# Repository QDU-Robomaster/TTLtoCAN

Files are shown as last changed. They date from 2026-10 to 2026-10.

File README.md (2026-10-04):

# 项目名称
TTLtoCANforTOF

## 项目简介
面向 ToF 设备的 TTL UART 转 CAN 通信模块，设计目标是通过 24V 输入为 ToF 提供 5V 电源，并由 STM32 完成串口数据与 CAN 报文之间的转换。

## PCB预览

以下预览基于 2026-10-04 23:51 保存的 PCB 文件重新生成。部分器件未配置三维模型，实际装配以封装和 BOM 为准。

正面：

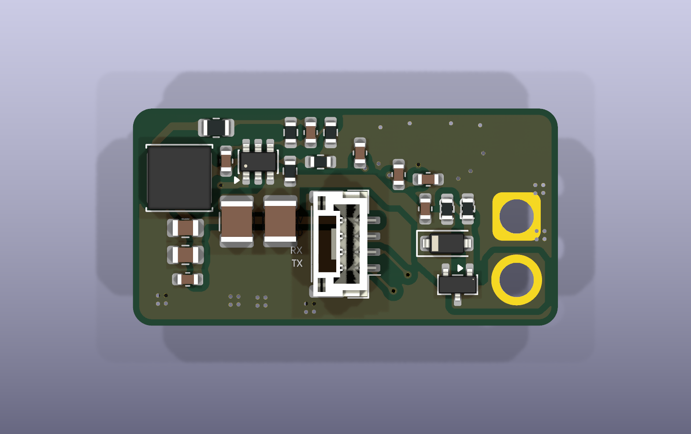
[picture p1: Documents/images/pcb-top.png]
PCB 正面


背面：

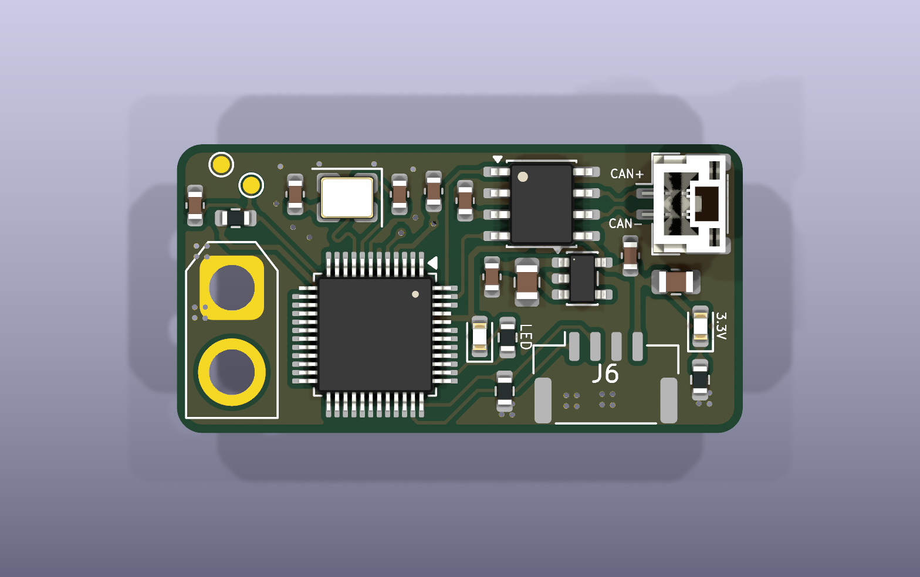
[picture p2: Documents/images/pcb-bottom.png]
PCB 背面


## 主要参数
PCB 尺寸  36.00 × 20.05 mm，圆角矩形 
层数 / 板厚  2 层 / 1.6 mm 
输入电源  设计标称 24V，经 J4 输入 
ToF 电源  设计目标 5V，经 J3 第 4 脚输出 
板上逻辑电源  3.3V 
主控  STM32G0B1CBTx，LQFP-48 
通信接口  UART（J3）、CAN（J2） 
调试接口  SWD（J6） 
## 接口定义
J4：电源输入 AMASS XT30U-F，2Pin  
    1：GND；
    2：VCC_IN（标称 24V 输入） 
J2：CAN  JST GH，2Pin，1.25 mm  
    1：CAN− / CAN_L；
    2：CAN+ / CAN_H 
J3：ToF  JST GH，4Pin，1.25 mm  
    1：USART1_TX（模块输出，接设备 RX）；
    2：USART1_RX（模块输入，接设备 TX）；
    3：GND；
    4：5V 电源输出 
J6：SWD  Molex CLIK-Mate 502386-0470，4Pin，1.25 mm  
    1：SWDIO；
    2：SWCLK；
    3：GND；
    4：3.3V 参考电源 
## 项目扩展叙述

电源部分通过 TPS54202 将输入电源降压至设计目标 5V，再由 ME6211 产生板上 3.3V。STM32 连接 ToF 的 UART，并通过 CAN 收发器接入总线。通信转换需要配套固件，当前仓库未提供固件及协议定义。

详细的接口接线、工程打开方式、生产资料与调试安排见 [工程说明文档](Documents/工程说明.md)。

## 主要器件
U1  TPS54202DDC  开关降压，设计用于产生 5V 
U2  ME6211C33M5  3.3V 线性稳压 
U3  STM32G0B1CBTx  通信处理主控 
U6  TCAN3413DR（当前 Value）  CAN 收发器
Q2  Si2309CDS-T1-GE3  输入侧 P 沟道 MOS 管 
D3  BZT52-C12  输入保护电路中的稳压管 
L1  15µH  降压电感 
Y1  X32258MSB  MCU 外部晶振
## 制造资料指路
制造和装配输出位于 [Production_documents/](Production_documents/)，各子目录用途见 [工程说明文档](Documents/工程说明.md)。
使用 KiCad 10.0.x 打开根目录的 [TTLtoCANforTOF.kicad_pro](TTLtoCANforTOF.kicad_pro)，再进入原理图或 PCB 编辑器。
 [TTLtoCANforTOF.kicad_sch](TTLtoCANforTOF.kicad_sch)  当前原理图 
 [TTLtoCANforTOF.kicad_pcb](TTLtoCANforTOF.kicad_pcb)  当前 PCB 
 [sym-lib-table](sym-lib-table)  项目符号库路径配置  [BOM/](BOM/)  设计物料清单 
 [Documents/](Documents/)  项目说明、预览图和检查报告 
 [3Dmodel/TTLtoCANforTOF.step](3Dmodel/TTLtoCANforTOF.step)  整板 STEP 模型 
 [Production_documents/](Production_documents/)  生产输出资料 
 [History/](History/)  历史工程快照，不作为当前生产依据

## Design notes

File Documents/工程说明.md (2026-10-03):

# TTLtoCANforTOF 工程说明

更新日期：2026-10-03。本文依据当前仓库中的原理图、PCB、BOM 和生产目录编写；设计目标与实测结果分开记录。

## 1. 项目用途

本工程用于将 ToF 设备的 TTL UART 数据接入 CAN 总线，同时利用外部标称 24V 电源为 ToF 提供设计目标为 5V 的电源输出。

STM32G0B1CBTx 负责串口数据接收、解析和 CAN 报文组织，CAN 收发器负责连接物理总线。

## 2. 系统组成与主要参数

电源路径：J4 电源输入 → 输入保护电路 → TPS54202 降压电路 → 5V；5V 分别供给 J3 的 ToF 电源接口和 ME6211 线性稳压器，后者产生板上 3.3V。

通信路径：J3 的 UART 信号 ↔ STM32G0B1 ↔ CAN 收发器 ↔ J2 的 CAN 总线。J6 提供 SWD 调试接口。

| 项目 | 当前设计 |
| --- | --- |
| 工程名称 | TTLtoCANforTOF |
| 设计工具 | KiCad 10.0.x；已有导出和检查使用 10.0.5 |
| 板框尺寸 | 36.00 × 20.05 mm |
| 外形 | 圆角矩形，板框圆角半径 1.5 mm |
| PCB 层数 / 板厚 | 2 层 / 1.6 mm |
| 电源输入 | 标称 24V，J4 输入 |
| ToF 电源输出 | 设计目标 5V，J3 第 4 脚 |
| 板上逻辑电源 | 3.3V |
| 主控 | STM32G0B1CBTx，LQFP-48 |
| 外设接口 | UART、CAN、SWD |

## 3. 接口与连接方式

### J4：电源输入

连接器封装：AMASS XT30U-F，2Pin。

| 引脚 | 网络 | 用途 |
| --- | --- | --- |
| 1 | GND | 电源负极 |
| 2 | VCC_IN | 标称 24V 电源正极 |

### J2：CAN 接口

连接器封装：JST GH，2Pin，1.25 mm 间距。

| 引脚 | 网络 | 用途 |
| --- | --- | --- |
| 1 | CAN− | CAN_L |
| 2 | CAN+ | CAN_H |

### J3：ToF 接口

连接器封装：JST GH，4Pin，1.25 mm 间距。

| 引脚 | 网络 | 用途 |
| --- | --- | --- |
| 1 | USART1_TX | 模块串口发送，接 ToF 的 RX |
| 2 | USART1_RX | 模块串口接收，接 ToF 的 TX |
| 3 | GND | ToF 信号地及供电地 |
| 4 | 5V | ToF 电源输出 |

### J6：SWD 调试接口

连接器封装：Molex CLIK-Mate 502386-0470，4Pin，1.25 mm 间距。

| 引脚 | 网络 | 用途 |
| --- | --- | --- |
| 1 | SWDIO | SWD 数据 |
| 2 | SWCLK | SWD 时钟 |
| 3 | GND | 调试器参考地 |
| 4 | +3.3V | 目标板电压参考 |

## 4. 主要器件

| 位号 | 型号 / 数值 | 作用 |
| --- | --- | --- |
| U1 | TPS54202DDC | 开关降压，设计用于 24V 转 5V |
| U2 | ME6211C33M5 | 产生板上 3.3V |
| U3 | STM32G0B1CBTx | 串口和 CAN 通信处理 |
| U6 | TCAN3413DR（当前 Value） | CAN 总线收发器 |
| Q2 | Si2309CDS-T1-GE3 | 输入侧 P 沟道 MOS 管 |
| D3 | BZT52-C12 | 输入保护电路中的稳压管 |
| L1 | 15µH | 降压储能电感 |
| Y1 | X32258MSB | MCU 外部晶振 |

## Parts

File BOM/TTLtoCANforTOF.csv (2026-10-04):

编号 | 位号 | 封装 | 数量 | 名称 | 供应商编号
1 | C1, C2, C10, C12, C13, C14, C18, C19, C20, C21 | C_0603_1608Metric | 10 | 0.1uF
2 | C3, C4 | C_1210_3225Metric | 2 | 22uF
3 | C6, C8, C11 | C_0805_2012Metric | 3 | 22uF
4 | C7 | C_0603_1608Metric | 1 | 75pF
5 | C9 | C_0805_2012Metric | 1 | 10uF
6 | C15 | C_0603_1608Metric | 1 | 4.7uF
7 | C16, C17 | C_0603_1608Metric | 2 | 22pF
8 | D1, D2 | LED_0603_1608Metric | 2 | LED
9 | D3 | D_SOD-123 | 1 | BZT52-C12
10 | J2 | JST_GH_BM02B-GHS-TBT_1x02-1MP_P1.25mm_Vertical | 1 | CAN
11 | J3 | JST_GH_BM04B-GHS-TBT_1x04-1MP_P1.25mm_Vertical | 1 | TOF
12 | J4 | AMASS_XT30U-F_1x02_P5.0mm_Vertical | 1 | XT30
13 | J6 | Molex_CLIK-Mate_502386-0470_1x04-1MP_P1.25mm_Horizontal | 1 | SWD
14 | L1 | L_APV_ANR5020 | 1 | 15uH
15 | Q2 | SOT-23 | 1 | Si2309CDS-T1-GE3
16 | R1 | R_0603_1608Metric | 1 | 500kΩ
17 | R2, R4, R7, R9 | R_0603_1608Metric | 4 | 100kΩ
18 | R3 | R_0805_2012Metric | 1 | 0Ω
19 | R5 | R_0603_1608Metric | 1 | 13.3kΩ
20 | R6, R8 | R_0603_1608Metric | 2 | 10kΩ
21 | R10, R11 | R_0603_1608Metric | 2 | 1kΩ
22 | TP1 | TestPoint_Pad_D1.0mm | 1 | RST
23 | TP2 | TestPoint_Pad_D1.0mm | 1 | GND
24 | U1 | SOT-23-6 | 1 | TPS54202DDC
25 | U2 | SOT-23-5 | 1 | ME6211C33M5
26 | U3 | LQFP-48_7x7mm_P0.5mm | 1 | STM32G0B1CBTx
27 | U6 | SOIC-8_3.9x4.9mm_P1.27mm | 1 | TCAN3413DR
28 | Y1 | Crystal_SMD_3225-4Pin_3.2x2.5mm | 1 | X32258MSB

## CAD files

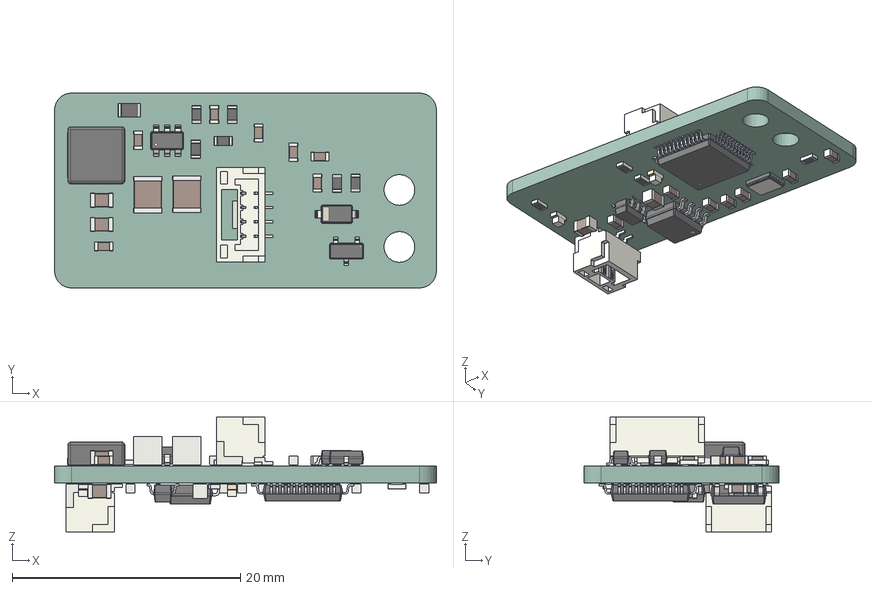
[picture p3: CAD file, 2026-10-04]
3Dmodel/TTLtoCANforTOF.step
33.5 x 17.1 x 10.1 mm
R_0603_1608Metric x 10
C_0603_1608Metric x 14
SOT-23
D_SOD-123
R_0805_2012Metric
C_0805_2012Metric x 4
JST_BM04B_GHS_TBT
L_APV_ANR5020
SOT-23-6
C_1210_3225Metric x 2
LED_0603_1608Metric x 2
SOIC-8_3.9x4.9mm_P1.27mm
JST_BM02B_GHS_TBT
LQFP-48_7x7mm_P0.5mm
Crystal_SMD_3225-4Pin_3.2x2.5mm
SOT-23-5
TTL438A_PCB

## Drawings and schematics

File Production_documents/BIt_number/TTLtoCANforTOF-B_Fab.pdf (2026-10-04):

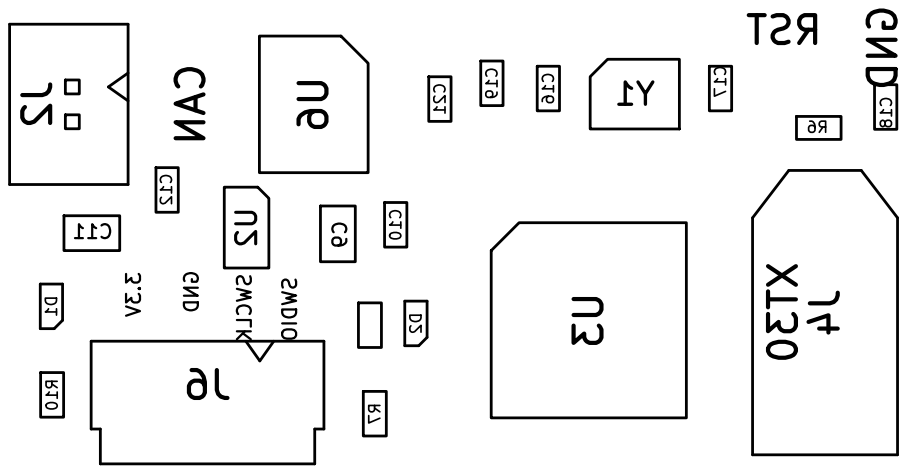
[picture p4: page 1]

3.3V GND SWCLK SWDIO J6 D1 R7 C12 D2 C19 C16 RST

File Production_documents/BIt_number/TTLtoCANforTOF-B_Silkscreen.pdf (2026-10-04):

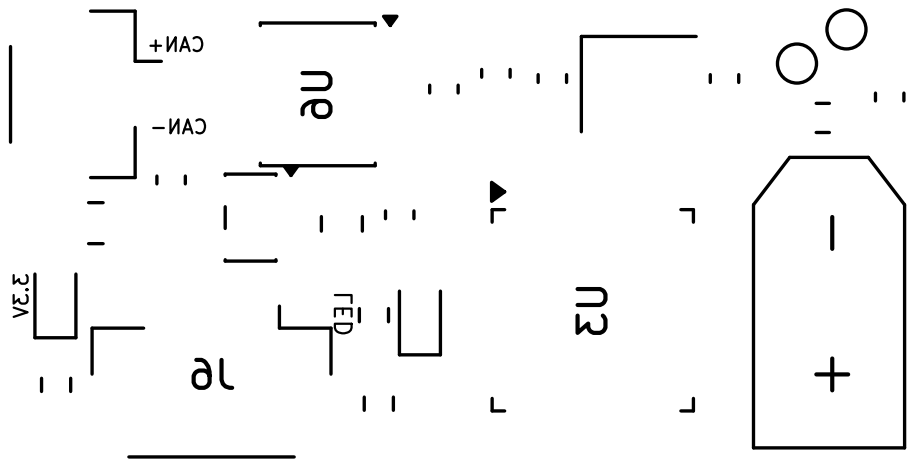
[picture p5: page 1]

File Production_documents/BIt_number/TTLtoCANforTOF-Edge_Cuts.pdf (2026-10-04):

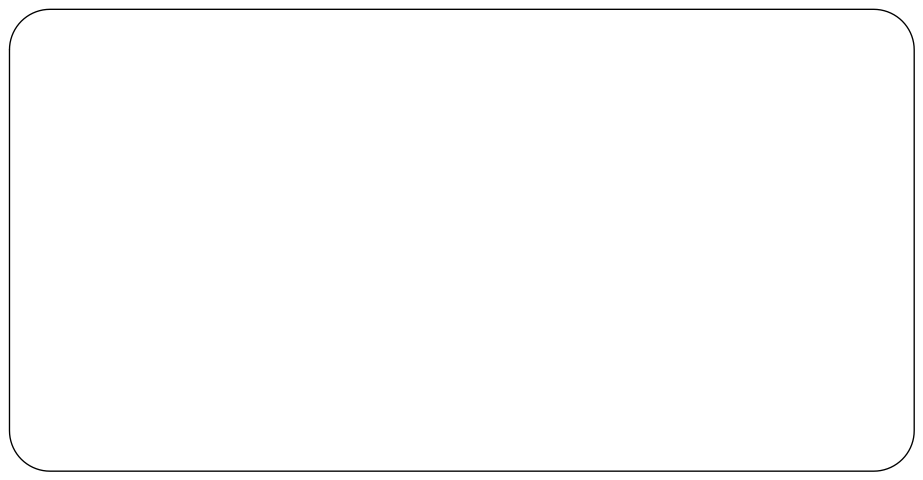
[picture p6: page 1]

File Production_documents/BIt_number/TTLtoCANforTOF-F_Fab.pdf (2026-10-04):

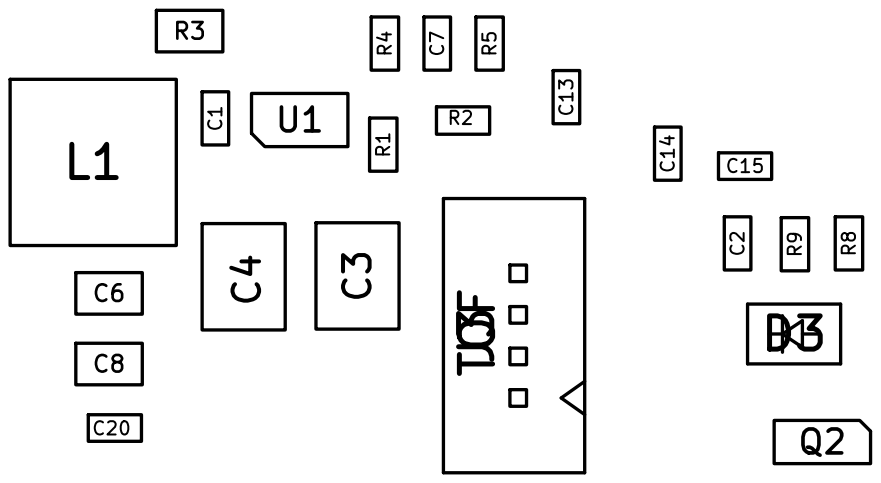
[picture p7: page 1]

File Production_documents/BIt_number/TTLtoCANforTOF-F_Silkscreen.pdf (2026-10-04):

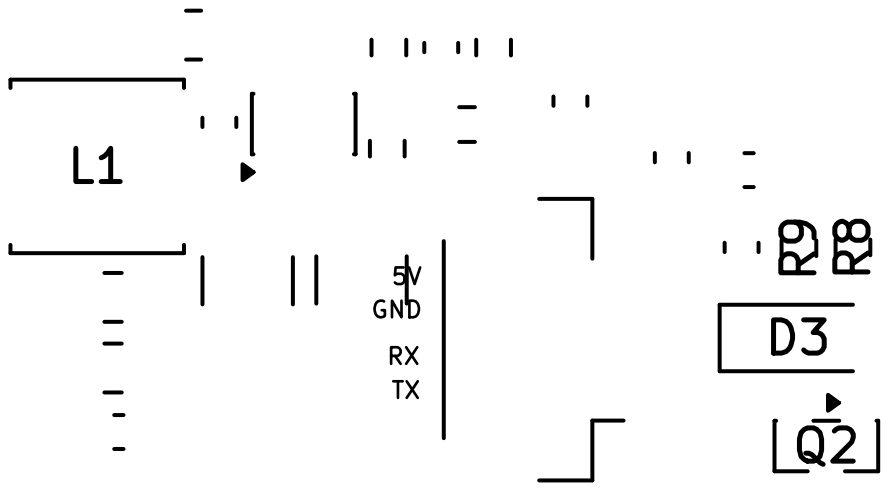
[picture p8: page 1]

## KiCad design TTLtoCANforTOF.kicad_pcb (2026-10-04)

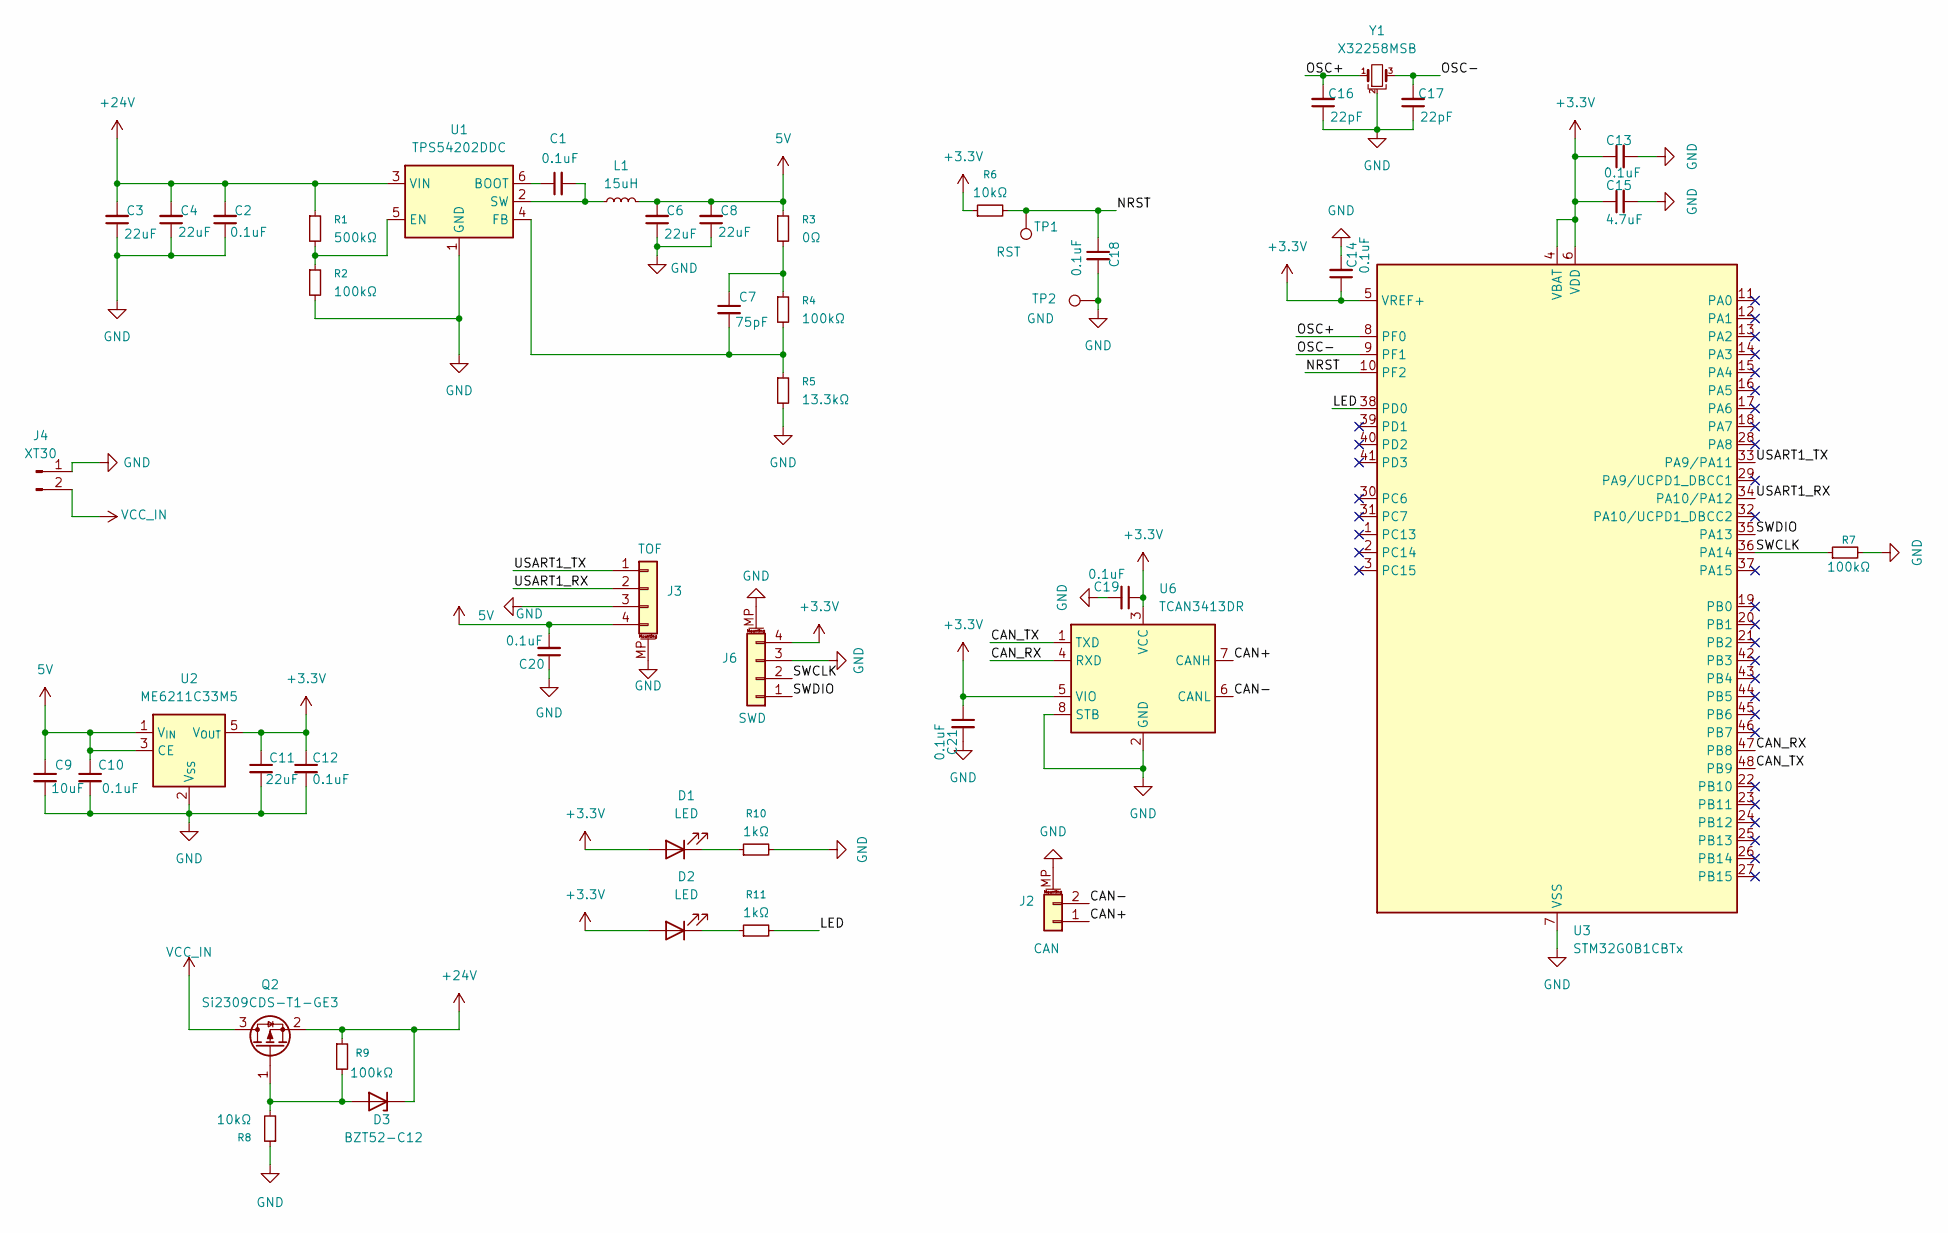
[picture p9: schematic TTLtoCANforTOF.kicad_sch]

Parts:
C1, C2, C10, C12, C13, C14, C18, C19, C20, C21: 0.1uF; C_0603_1608Metric
C3, C4: 22uF; C_1210_3225Metric
C6, C8, C11: 22uF; C_0805_2012Metric
C7: 75pF; C_0603_1608Metric
C9: 10uF; C_0805_2012Metric
C15: 4.7uF; C_0603_1608Metric
C16, C17: 22pF; C_0603_1608Metric
D1, D2: LED; LED_0603_1608Metric
D3: BZT52-C12; D_SOD-123
J2: CAN; JST_GH_BM02B-GHS-TBT_1x02-1MP_P1.25mm_Vertical
J3: TOF; JST_GH_BM04B-GHS-TBT_1x04-1MP_P1.25mm_Vertical
J4: XT30; AMASS_XT30U-F_1x02_P5.0mm_Vertical
J6: SWD; Molex_CLIK-Mate_502386-0470_1x04-1MP_P1.25mm_Horizontal
L1: 15uH; L_APV_ANR5020
Q2: Si2309CDS-T1-GE3; SOT-23
R1: 500kΩ; R_0603_1608Metric
R2, R4, R7, R9: 100kΩ; R_0603_1608Metric
R3: 0Ω; R_0805_2012Metric
R5: 13.3kΩ; R_0603_1608Metric
R6, R8: 10kΩ; R_0603_1608Metric
R10, R11: 1kΩ; R_0603_1608Metric
TP1: RST; TestPoint_Pad_D1.0mm
TP2: GND; TestPoint_Pad_D1.0mm
U1: TPS54202DDC; SOT-23-6
U2: ME6211C33M5; SOT-23-5
U3: STM32G0B1CBTx; LQFP-48_7x7mm_P0.5mm
U6: TCAN3413DR; SOIC-8_3.9x4.9mm_P1.27mm
Y1: X32258MSB; Crystal_SMD_3225-4Pin_3.2x2.5mm

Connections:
5V: C6.2, C8.2, C9.1, C10.1, C20.2, J3.4, L1.1, R3.1, U2.1 (V_{IN}), U2.3 (CE)
+3.3V: C11.1, C12.1, C13.1, C14.1, C15.1, C19.1, C21.1, D1.2 (A), D2.2 (A), J6.4, R6.1, U2.5 (V_{OUT}), U3.4 (VBAT), U3.5 (VREF+), U3.6 (VDD), U6.3 (VCC), U6.5 (VIO)
+24V: C2.2, C3.2, C4.2, D3.1 (K), Q2.2 (S), R1.1, R9.1, U1.3 (VIN)
/CAN+: J2.1, U6.7 (CANH)
/CAN-: J2.2, U6.6 (CANL)
/CAN_RX: U3.47 (PB8), U6.4 (RXD)
/CAN_TX: U3.48 (PB9), U6.1 (TXD)
/LED: R11.2, U3.38 (PD0)
/NRST: C18.1, R6.2, TP1.1 (1_1), U3.10 (PF2)
/OSC+: C16.2, U3.8 (PF0), Y1.1
/OSC-: C17.2, U3.9 (PF1), Y1.3
/SWCLK: J6.2, R7.1, U3.36 (PA14)
/SWDIO: J6.1, U3.35 (PA13)
/USART1_RX: J3.2, U3.34 (PA10/PA12)
/USART1_TX: J3.1, U3.33 (PA9/PA11)
GND: C2.1, C3.1, C4.1, C6.1, C8.1, C9.2, C10.2, C11.2, C12.2, C13.2, C14.2, C15.2, C16.1, C17.1, C18.2, C19.2, C20.1, C21.2, J2.MP (MountPin), J3.3, J3.MP (MountPin), J4.1, J6.3, J6.MP (MountPin), R2.2, R5.2, R7.2, R8.1, R10.2, TP2.1 (1_1), U1.1 (GND), U2.2 (V_{SS}), U3.7 (VSS), U6.2 (GND), U6.8 (STB), Y1.2, Y1.4
unnamed: C7.1, R3.2, R4.1
unnamed: D1.1 (K), R10.1
unnamed: D2.1 (K), R11.1
unnamed: D3.2 (A), Q2.1 (G), R8.2, R9.2
unnamed: C1.1, U1.6 (BOOT)
unnamed: R1.2, R2.1, U1.5 (EN)
unnamed: C7.2, R4.2, R5.1, U1.4 (FB)
unnamed: C1.2, L1.2, U1.2 (SW)
VCC_IN: J4.2, Q2.3 (D)

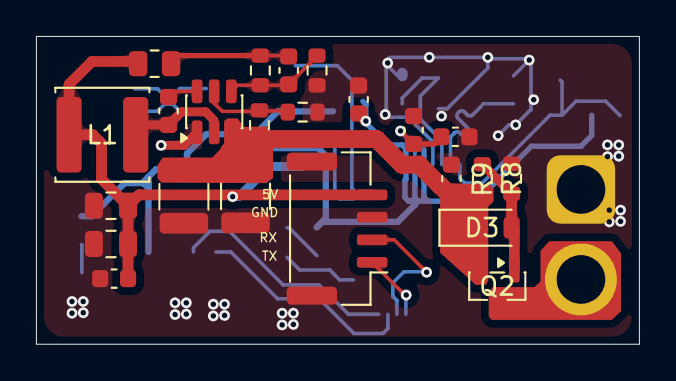
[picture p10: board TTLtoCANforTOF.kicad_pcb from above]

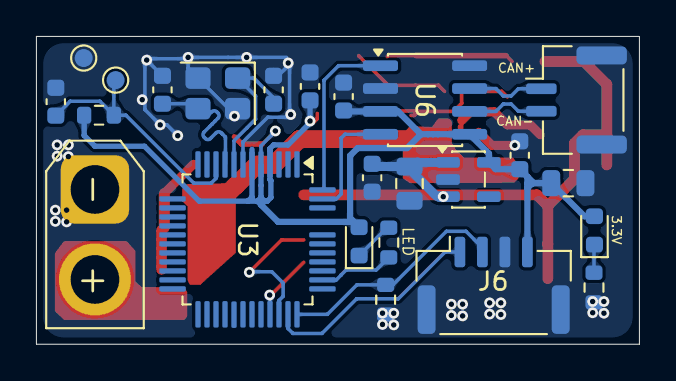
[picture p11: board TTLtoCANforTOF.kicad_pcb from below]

Board: 2 copper layers, 33.5 x 17.1 mm, 47 parts (24 on the bottom side), 25 nets.
